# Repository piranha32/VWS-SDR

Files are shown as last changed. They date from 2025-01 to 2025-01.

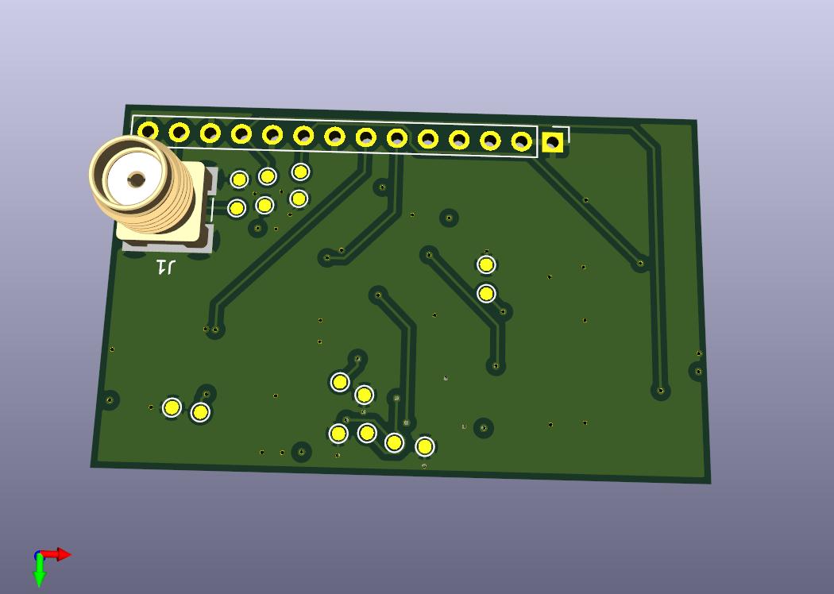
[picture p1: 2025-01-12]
VWS-SDR-breadboard/VWS-SDR-JRR-design-top v0.1.jpg

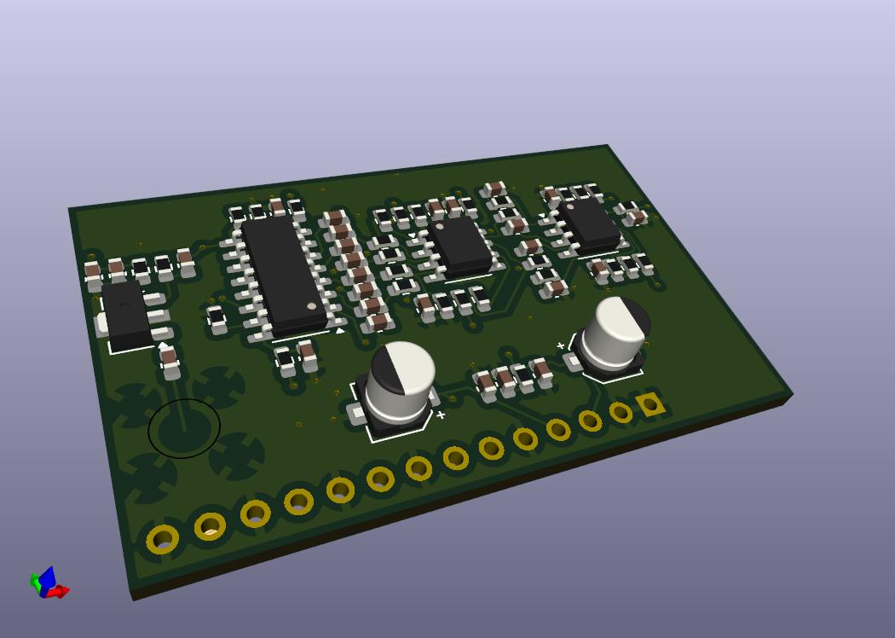
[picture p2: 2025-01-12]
VWS-SDR-breadboard/VWS-SDR-JRR-design v0.1.jpg

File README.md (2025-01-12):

# Vienna Wireless Society Software Defined Receiver (VWS-SDR)
Compact breadboard module version of the VWS SDR frontend. 

Changes compared to the source design:
- Removed clock generator and controller modules. This module implements only downconversion and filtering.
- Added pin header for installation on a breadboard.
- Added 3.3V regulator to provide voltage used by the multiplexer chip. The voltage is also available on the pin header, and can be used to power the clock generator module.
- Replaced electrolytic capacitors with SMD versions.
- All remaining passives use 0603 footprints.

# Original description

This repository contains the files for a 2025 project by the [Vienna Wireless Society's](https://viennawireless.net/wp/) Makers Group. This project aims to build the RF front end of a software defined receiver covering the HF bands. The goals of the project are: 

1. Learn how to use KiCAD, and 
2. Learn surface mount assembly techniques. 

The VWS-SDR design draws heavily from the RF board of the T41-EP Software Defined Transceiver (SDT) originally designed by Al Peter-AC8GY and Jack Purdum-W8TEE. The T41-EP is a self-contain SDT that does not require an external PC, laptop, or tablet to use. Al and Jack wrote a book, available on [Amazon](https://www.amazon.com/dp/B0D25FV48C), describing the theory and operation of the T41-EP.

## Design overview 

The VWS-SDR has stages shown in the block diagram below.

1. A gain stage based on the [GALI-S66+](https://www.minicircuits.com/WebStore/dashboard.html?model=GALI-S66%2B) MMIC amplifier.
2. A [Tayloe Mixer](http://norcalqrp.org/files/Tayloe_mixer_x3a.pdf) that uses quadrature signals generated by a [Si5351](https://www.digikey.com/en/htmldatasheets/production/1316951/0/0/1/si535x-tmstk) clock generator and a [74CBTLV3253](https://www.ti.com/product/SN74CBTLV3253) 2-channel analog multiplexer to mix the RF signals to IF.
3. An anti-aliasing low-pass filter followed by a USB soundcard to digitize the IF signal.
4. Demodulation will be performed in software using [quisk](http://james.ahlstrom.name/quisk/).

Block diagram for the VWS SDR

## Instructions

Download this repository to your computer. Open the `KiCad\VWS-SDR-ref-design.kicad_pro` file using the [KiCad](https://www.kicad.org/) EDA software package. This repository includes a few custom symbols and footprints which should automatically be added to your library lists by KiCad.

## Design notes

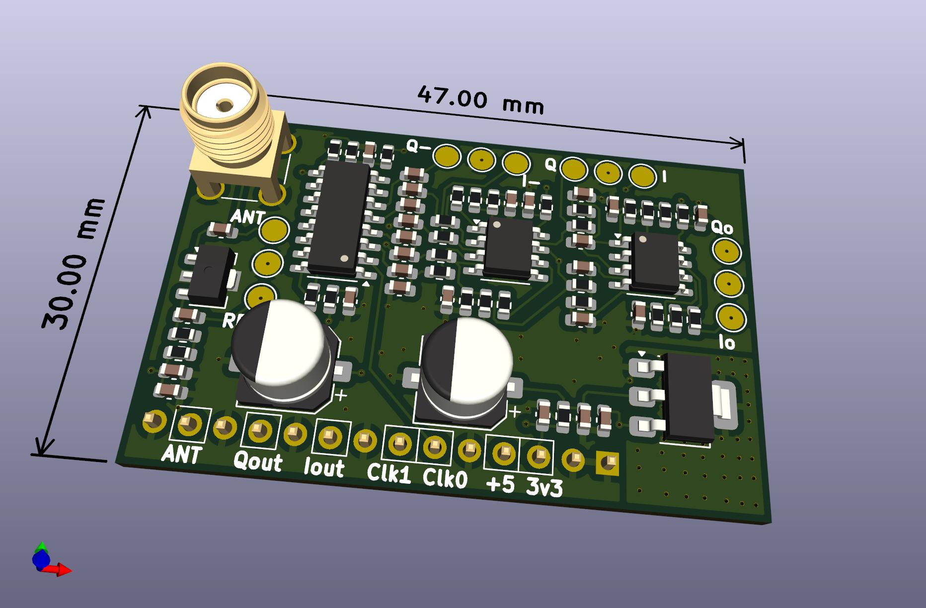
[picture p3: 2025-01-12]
VWS-SDR-breadboard/VWS-SDR-breadboard v1.0.jpg

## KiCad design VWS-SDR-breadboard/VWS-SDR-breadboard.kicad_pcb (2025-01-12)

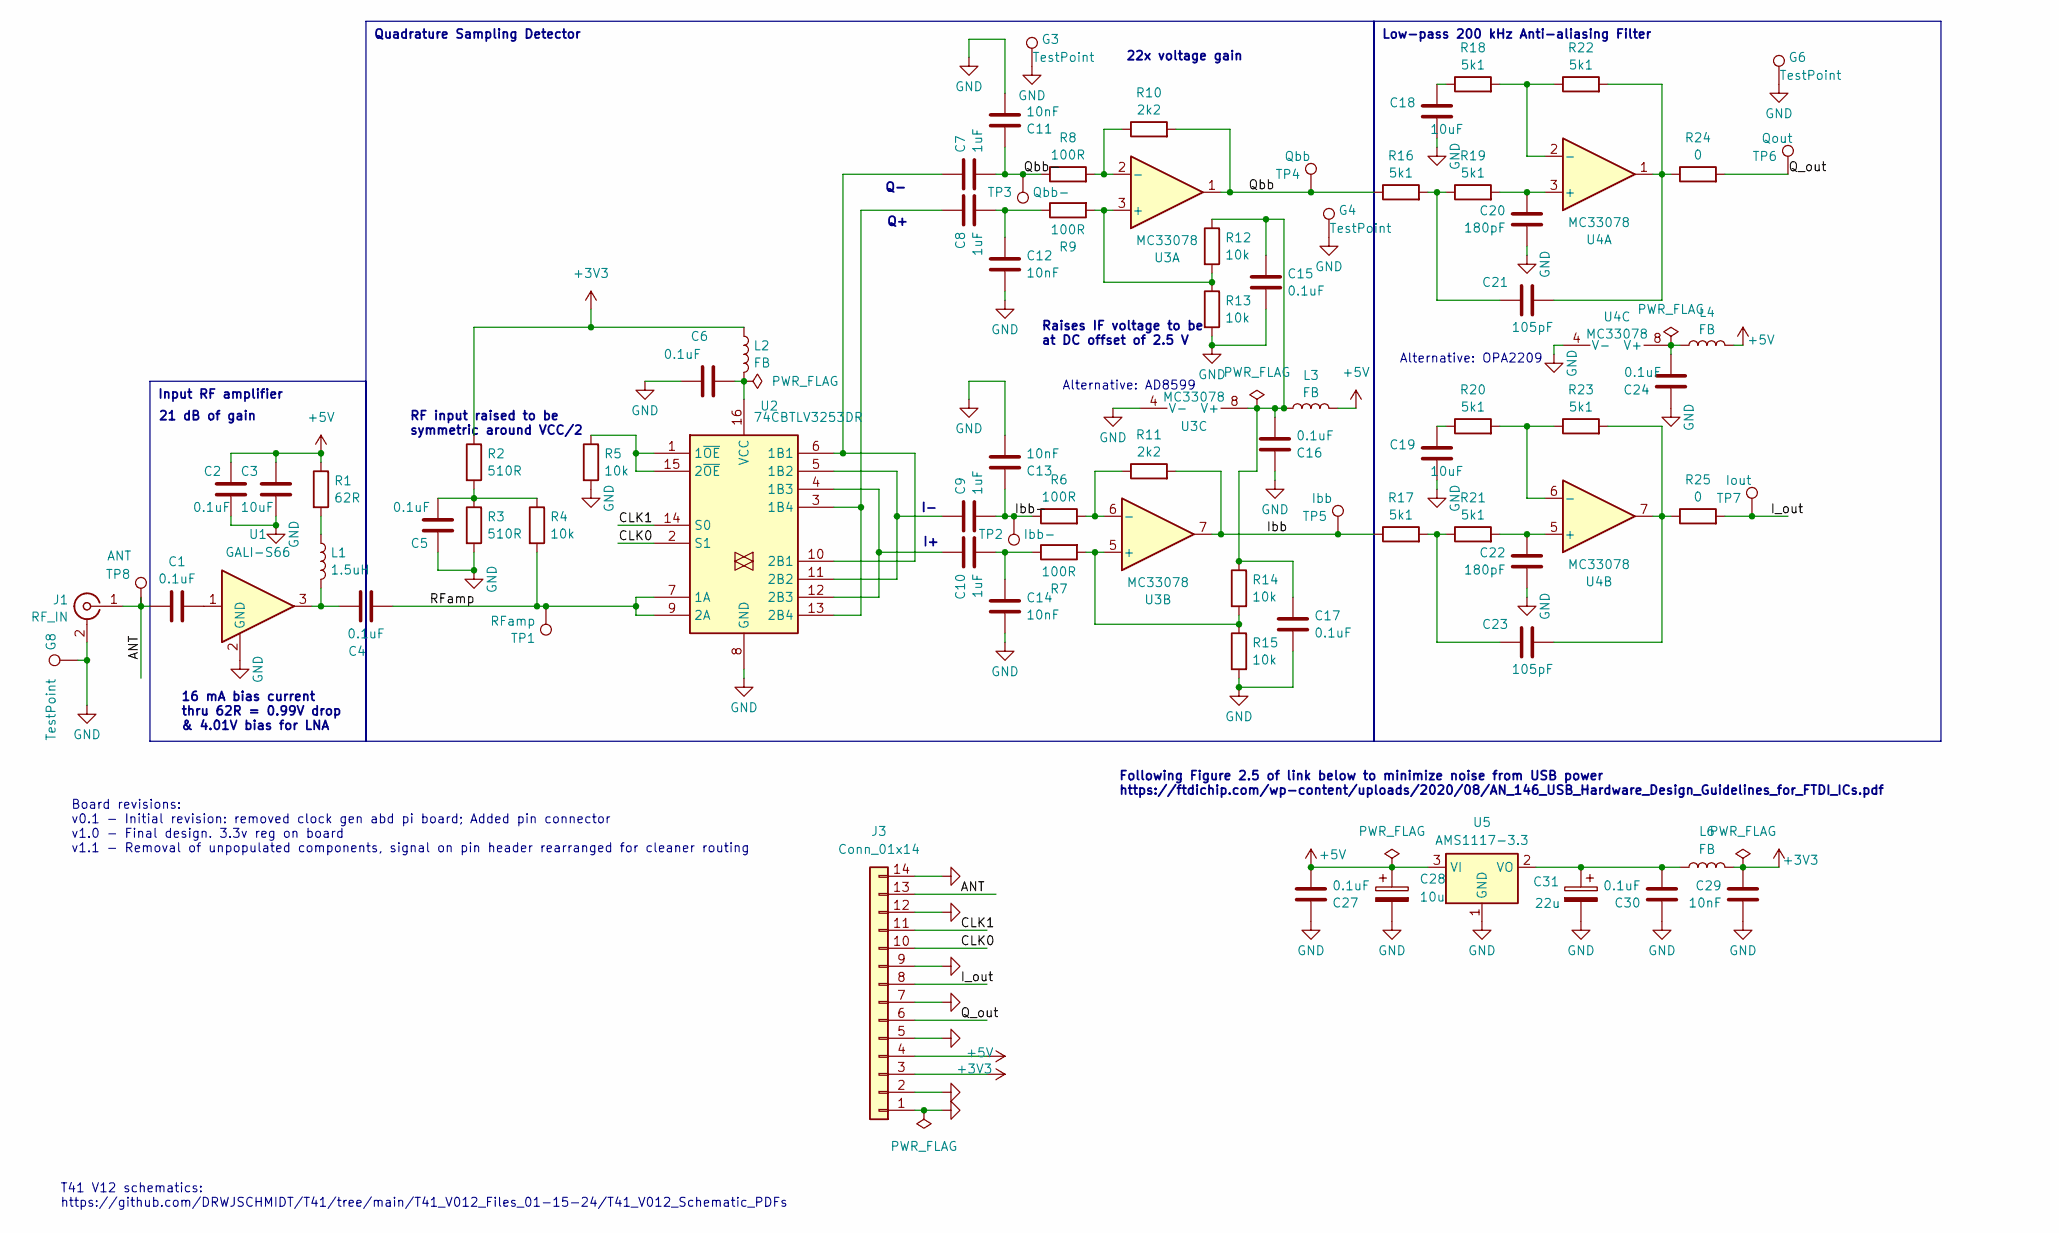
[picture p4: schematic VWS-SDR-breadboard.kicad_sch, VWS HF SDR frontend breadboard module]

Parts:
C1, C2, C4, C5, C6, C15, C16, C17, C24, C27, C30: 0.1uF; C_0603_1608Metric; Mouser Part Number C1206C104K5RACTU
C3, C18, C19: 10uF; C_0603_1608Metric; Mouser Part Number 80-C1206C106K4P
C7, C8, C9, C10: 1uF; C_0603_1608Metric; Mouser Part Number 187-CL31B105KBHNNNE
C11, C12, C13, C14, C29: 10nF; C_0603_1608Metric; Mouser Part Number 80-C1206C103K5R7210
C20, C22: 180pF; C_0603_1608Metric; Mouser Part Number 791-1206B181K160CT
C21, C23: 105pF; C_0603_1608Metric; Mouser Part Number 581-12065C101KAT2A
C28: 10u; CP_Elec_6.3x5.9; Mouser Part Number 80-ESK475M016AC3AA
C31: 22u; CP_Elec_6.3x5.9; Mouser Part Number 80-ESK475M016AC3AA
G3, G4, G6, G8: TestPoint; TestPoint_Pad_D2.0mm
J1: RF_IN; SMA_Amphenol_132134-11_Vertical; Mouser Part Number 712-CONSMA001-G
J3: Conn_01x14; PinHeader_1x14_P2.54mm_Vertical
L1: 1.5uH; R_0603_1608Metric; Mouser Part Number 81-LQM31PN1R5M00L
L2, L3, L4, L6: FB; R_0603_1608Metric; Mouser Part Number 875-HZ1206E601R-10
R1: 62R; R_0603_1608Metric; Mouser Part Number 652-CR1206FX-62R0ELF
R2, R3: 510R; R_0603_1608Metric; Mouser Part Number 652-CR1206FX-5100ELF
R4, R5, R12, R13, R14, R15: 10k; R_0603_1608Metric; Mouser Part Number 652-CR1206FX-1002ELF
R6, R7, R8, R9: 100R; R_0603_1608Metric; Mouser Part Number 652-CR1206FX-1000ELF
R10, R11: 2k2; R_0603_1608Metric; Mouser Part Number 652-CR1206FX-2201ELF
R16, R17, R18, R19, R20, R21, R22, R23: 5k1; R_0603_1608Metric; Mouser Part Number 652-CR1206JW-512ELF
R24, R25: 0; R_0603_1608Metric; Mouser Part Number 71-CRCW12060000Z0EAC
TP1: RFamp; TestPoint_Pad_D2.0mm
TP2: Ibb-; TestPoint_Pad_D2.0mm
TP3: Qbb-; TestPoint_Pad_D2.0mm
TP4: Qbb; TestPoint_Pad_D2.0mm
TP5: Ibb; TestPoint_Pad_D2.0mm
TP6: Qout; TestPoint_Pad_D2.0mm
TP7: Iout; TestPoint_Pad_D2.0mm
TP8: ANT; TestPoint_Pad_D2.0mm
U1: GALI-S66; SOT-89-3; Mouser Part Number 139-GALI-S66
U2: 74CBTLV3253DR; SOIC-16_3.9x9.9mm_P1.27mm; Mouser Part Number 595-SN74CBTLV3253DR
U3, U4: MC33078; SOIC-8_3.9x4.9mm_P1.27mm; Mouser Part Number 595-MC33078DR
U5: AMS1117-3.3; SOT-223-3_TabPin2

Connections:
+3V3: C29.2, J3.3, L2.1, L6.1, R2.1
+5V: C2.2, C3.2, C27.1, C28.1, J3.4, L3.2, L4.2, R1.1, U5.3 (VI)
/ANT: C1.1, J1.1 (In), J3.13, TP8.1
/CLK0: J3.10, U2.2 (S1)
/CLK1: J3.11, U2.14 (S0)
/I_out: J3.8, R25.2, TP7.1
/Ibb: R11.2, R17.1, TP5.1, U3.7
/Ibb-: C9.1, C13.2, R6.1, TP2.1
/Q_out: J3.6, R24.2, TP6.1
/Qbb: R10.2, R16.1, TP4.1, U3.1
/Qbb-: C7.1, C11.2, R8.1, TP3.1
/RFamp: C4.2, R4.2, TP1.1, U2.7 (1A), U2.9 (2A)
GND: C2.1, C3.1, C5.1, C6.1, C11.1, C12.1, C13.1, C14.1, C15.1, C16.2, C17.1, C18.1, C19.1, C20.1, C22.1, C24.2, C27.2, C28.2, C29.1, C30.2, C31.2, G3.1, G4.1, G6.1, G8.1, J1.2 (Ext), J3.1, J3.2, J3.5, J3.7, J3.9, J3.12, J3.14, R3.2, R5.2, R13.2, R15.2, U1.2 (GND), U2.8 (GND), U3.4 (V-), U4.4 (V-), U5.1 (GND)
unnamed: C1.2, U1.1
unnamed: C4.1, L1.2, U1.3
unnamed: C5.2, R2.2, R3.1, R4.1
unnamed: C10.1, C14.2, R7.1
unnamed: C8.1, C12.2, R9.1
unnamed: C18.2, R18.1
unnamed: C19.2, R20.1
unnamed: C21.1, R22.2, R24.1, U4.1
unnamed: C21.2, R16.2, R19.1
unnamed: C23.1, R23.2, R25.1, U4.7
unnamed: C23.2, R17.2, R21.1
unnamed: L1.1, R1.2
unnamed: C7.2, U2.6 (1B1), U2.10 (2B1)
unnamed: C9.2, U2.5 (1B2), U2.11 (2B2)
unnamed: C10.2, U2.4 (1B3), U2.12 (2B3)
unnamed: C8.2, U2.3 (1B4), U2.13 (2B4)
unnamed: R5.1, U2.1 (1~OE), U2.15 (2~OE)
unnamed: C6.2, L2.2, U2.16 (VCC)
unnamed: R9.2, R12.2, R13.1, U3.3 (+)
unnamed: R8.2, R10.1, U3.2 (-)
unnamed: R7.2, R14.2, R15.1, U3.5 (+)
unnamed: R6.2, R11.1, U3.6 (-)
unnamed: C15.2, C16.1, C17.2, L3.1, R12.1, R14.1, U3.8 (V+)
unnamed: C20.2, R19.2, U4.3 (+)
unnamed: R18.2, R22.1, U4.2 (-)
unnamed: C22.2, R21.2, U4.5 (+)
unnamed: R20.2, R23.1, U4.6 (-)
unnamed: C24.1, L4.1, U4.8 (V+)
unnamed: C30.1, C31.1, L6.2, U5.2 (VO)

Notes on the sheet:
Low-pass 200 kHz Anti-aliasing Filter
Quadrature Sampling Detector
Input RF amplifier
Raises IF voltage to be at DC offset of 2.5 V
T41 V12 schematics: https://github.com/DRWJSCHMIDT/T41/tree/main/T41_V012_Files_01-15-24/T41_V012_Schematic_PDFs
Following Figure 2.5 of link below to minimize noise from USB power https://ftdichip.com/wp-content/uploads/2020/08/AN_146_USB_Hardware_Design_Guidelines_for_FTDI_ICs.pdf
Alternative: OPA2209
21 dB of gain
Board revisions: v0.1 - Initial revision: removed clock gen abd pi board; Added pin connector v1.0 - Final design. 3.3v reg on board v1.1 - Removal of unpopulated components, signal on pin header rearranged for cleaner routing
Alternative: AD8599
16 mA bias current thru 62R = 0.99V drop & 4.01V bias for LNA
22x voltage gain
RF input raised to be symmetric around VCC/2

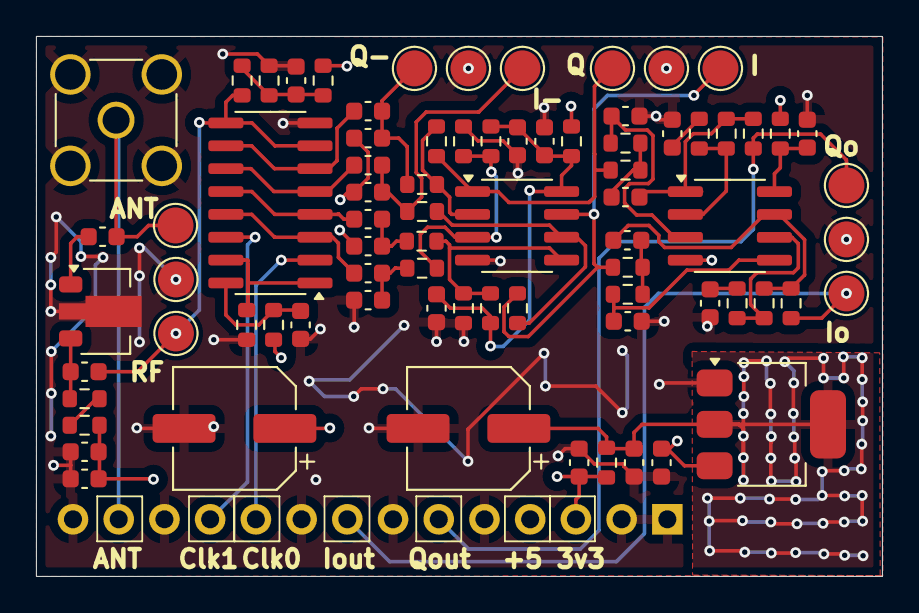
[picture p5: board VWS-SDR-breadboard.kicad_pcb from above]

Board: 4 copper layers, 47.0 x 30.0 mm, 78 parts (1 on the bottom side), 42 nets.

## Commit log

2025-01-10 Cleaned up the schematic (removed unnecessary components), replaced R/C footprints with 0603, replaced testpoints wit smd footprints, made mounting holes smaller
    [VWS-SDR-ref-design.kicad_sch]
2025-01-12 breadboard pcb v 1.0
    [VWS-SDR-breadboard.kicad_pcb, VWS-SDR-breadboard.kicad_sch]
2025-01-12 Board cleanup; Updated schematic info block
    [VWS-SDR-breadboard.kicad_pcb, VWS-SDR-breadboard.kicad_sch]
2025-01-12 v1.1: - Changed order of pins on the connector to simplify routing. I/Q should be closer to the power pins. clock should be closer to the antenna - Added GND fill on the Vcc layer under the antenna t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
    [VWS-SDR-breadboard.kicad_pcb, VWS-SDR-breadboard.kicad_sch]
2025-01-12 Added missing via to GND
    [VWS-SDR-breadboard.kicad_pcb]
